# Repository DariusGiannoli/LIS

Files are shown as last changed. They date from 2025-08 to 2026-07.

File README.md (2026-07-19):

# LIS Haptic System

Firmware and Python APIs for controlling a 32-actuator haptic system over USB
serial or Bluetooth Low Energy (BLE).

The final implementation uses a three-byte command protocol, 32 intensity
levels, eight frequency levels, and sine or square waveforms.

## Architecture

```text
PC application
    |
    | USB serial or BLE
    v
ESP32-S3 controller
    |
    | 4 UART subchains, 8 actuators per subchain
    v
PIC16F18313 vibration units
```

## Repository structure

- `firmware/pic/` — PIC16F18313 actuator firmware and NeoPixel driver.
- `firmware/serial/` — ESP32-S3 USB serial controller.
- `firmware/ble/` — ESP32-S3 BLE controller.
- `python/` — Serial and BLE Python APIs.
- `3D/` — Final left and right enclosure models.
- `docs/` — Protocol and waveform documentation.

## Capabilities

- 32 individually addressable actuators (`0` to `31`).
- 32 intensity levels (`0` to `31`, encoded on five bits).
- Eight frequency levels (`0` to `7`, encoded on three bits).
- Sine and square waveforms.
- Individual and batched start/stop commands.
- USB serial and BLE transports.

## Requirements

### Python

- Python 3.9 or newer.
- `pyserial` for USB serial control.
- `bleak` for BLE control.

```bash
python3 -m venv .venv
source .venv/bin/activate
pip install -r requirements.txt
```

### ESP32-S3

- Arduino IDE or Arduino CLI with the ESP32 board package.
- Adafruit NeoPixel library.
- EspSoftwareSerial library.

### PIC16F18313

- MPLAB X IDE.
- MPLAB XC8 compiler.

Create an XC8 project containing all files from `firmware/pic/`, then flash the
same firmware to each vibration unit.

## Flashing the controller

Choose one ESP32-S3 controller firmware:

- USB serial: `firmware/serial/controller.ino`
- Bluetooth LE: `firmware/ble/controller.ino`

Both controllers translate the same PC-side three-byte frames into commands for
the four PIC UART subchains.

## Serial example

```python
from python.serial_api import SERIAL_API

api = SERIAL_API()
devices = api.get_serial_devices()

if not devices:
    raise RuntimeError("No serial controller found")

api.connect_serial_device(devices[0])

# Start actuator 0: sine wave, intensity 16/31, frequency index 3.
api.send_command(addr=0, duty=16, freq=3, start_or_stop=1, wave=1)

# Stop actuator 0.
api.send_command(addr=0, duty=0, freq=3, start_or_stop=0, wave=1)

api.disconnect_serial_device()
```

## BLE example

Flash `firmware/ble/controller.ino`. The controller advertises as
`VibraForge-BLE`.

```python
from python.ble_api import BLE_API

api = BLE_API()

if not api.connect_ble_device():
    raise RuntimeError("VibraForge-BLE not found")

api.send_command(addr=0, duty=16, freq=3, start_or_stop=1, wave=1)
api.send_command(addr=0, duty=0, freq=3, start_or_stop=0, wave=1)
api.disconnect_ble_device()
```

## Protocol

Commands sent from the PC contain three bytes:

| Byte | Content |
| --- | --- |
| 1 | Waveform, UART group, and start/stop mode |
| 2 | Actuator address inside the group |
| 3 | Five-bit intensity and three-bit frequency |

See [docs/protocol.md](docs/protocol.md) for the complete bit layout and
frequency table. See [docs/waveforms.md](docs/waveforms.md) for the sine and
square control strategies.

## Safety

- Always send a STOP command after a test.
- Avoid leaving actuators at high intensity for extended periods.
- Verify the motor supply and UART wiring before flashing or testing.
- Start new hardware tests at a low intensity.

## Legacy code

Previous experiments, ESP-NOW prototypes, and development versions are
preserved on the `legacy` branch and in the Git history. `main` contains only
the consolidated pre-hackathon implementation.

## Contact

Darius Giannoli — darius.giannoli(at)epfl.ch

### Acknowledgments

Grateful for Dr. Yang Chen's supervision and for Gabriel Taieb for his contributions to this work

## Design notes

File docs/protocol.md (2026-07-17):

# Three-byte command protocol

The Python APIs send one three-byte frame for each actuator command. Both the
USB serial and BLE controllers accept the same format.

## PC to ESP32-S3

### Byte 1 — waveform, group, and mode

```text
bit:   7   6   5   4   3   2   1   0
       W   0  G3  G2  G1  G0  M1  M0
```

- `W`: waveform (`0` = square, `1` = sine).
- `G`: UART subchain (`0` to `3`).
- `M`: mode (`00` = stop, `01` = start, `10` = soft stop).

### Byte 2 — local actuator address

```text
bit:   7   6   5   4   3   2   1   0
       0   0  A5  A4  A3  A2  A1  A0
```

The current hardware uses local addresses `0` to `7`. A global actuator address
is converted with:

```text
group = address // 8
local address = address % 8
```

### Byte 3 — intensity and frequency

```text
bit:   7   6   5   4   3   2   1   0
      D4  D3  D2  D1  D0  F2  F1  F0
```

- `D`: intensity (`0` to `31`).
- `F`: frequency index (`0` to `7`).

## ESP32-S3 to PIC16F18313

A STOP command is forwarded as one address byte:

```text
[local_address << 1 | 0]
```

A START command is forwarded as three bytes:

```text
[local_address << 1 | 1]
[1 | intensity on five bits]
[1 | waveform | frequency on three bits]
```

## Frequency indices

| Index | Approximate frequency |
| ---: | ---: |
| 0 | 123 Hz |
| 1 | 145 Hz |
| 2 | 170 Hz |
| 3 | 200 Hz |
| 4 | 235 Hz |
| 5 | 275 Hz |
| 6 | 322 Hz |
| 7 | 384 Hz |

The PIC firmware applies separate calibrated intensity lookup tables for sine
and square output.

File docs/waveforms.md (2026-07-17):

# Sine and square waveform control

The PIC16F18313 firmware supports two vibration modes. Both accept an intensity
value from `0` to `31`, but they apply it differently.

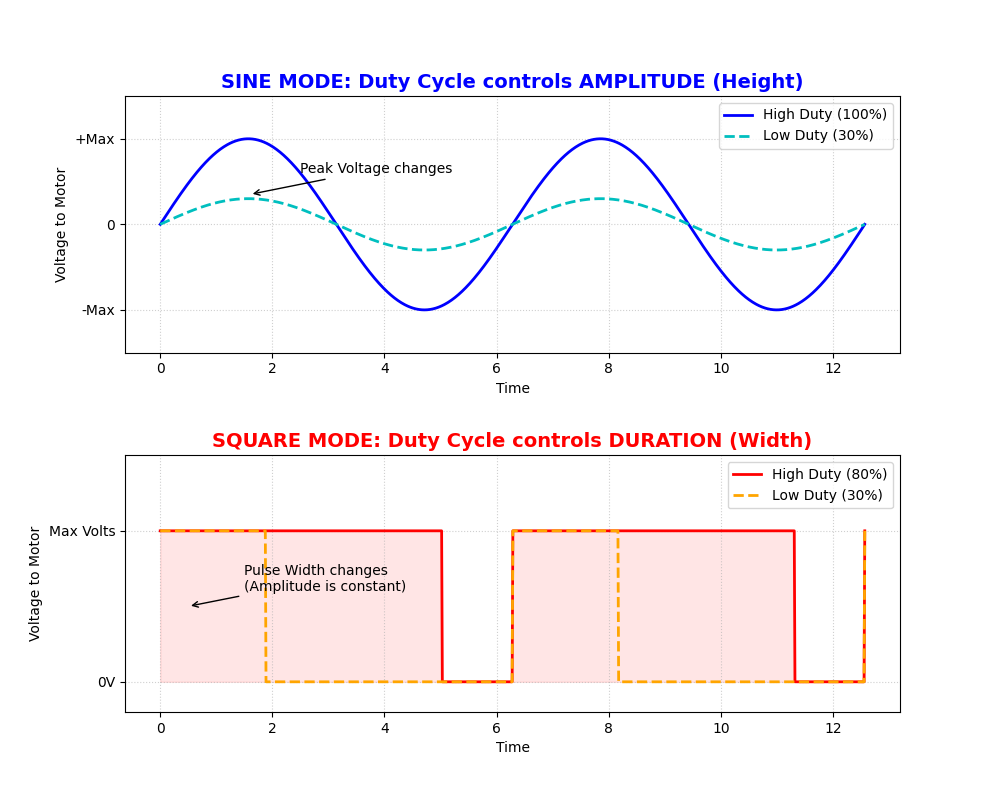
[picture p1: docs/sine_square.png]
Sine and square intensity comparison


## Square mode

Square mode controls the on-time of a full-power alternating signal. Increasing
the requested intensity widens each active portion of the waveform.

- Control domain: pulse width.
- Output: full voltage or off.
- Character: sharp and energetic.
- Typical use: impacts, alerts, and strong feedback.

The firmware uses a calibrated 32-entry lookup table so the perceived increase
is gradual at low levels and reaches full power at level `31`.

## Sine mode

Sine mode synthesizes a 64-sample waveform using a lookup table and sinusoidal
PWM. The requested intensity scales the peak amplitude.

- Control domain: amplitude.
- Output: PWM-reconstructed sine waveform.
- Character: smooth and precise.
- Typical use: textures and subtle feedback.

The H-bridge polarity changes at each zero crossing, while a high-frequency PWM
signal controls the magnitude of each sample.

## Summary

| Feature | Square | Sine |
| --- | --- | --- |
| Controlled quantity | Pulse width | Peak amplitude |
| Instantaneous output | Full power or off | Progressive PWM level |
| Perceived character | Sharp | Smooth |
| Intensity range | `0–31` | `0–31` |

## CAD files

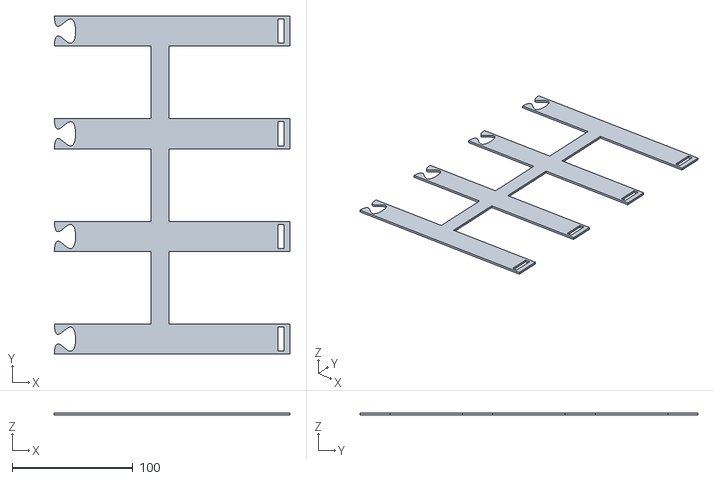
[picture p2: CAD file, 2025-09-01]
3D/Right.stl
195.0 x 279.8 x 2.00

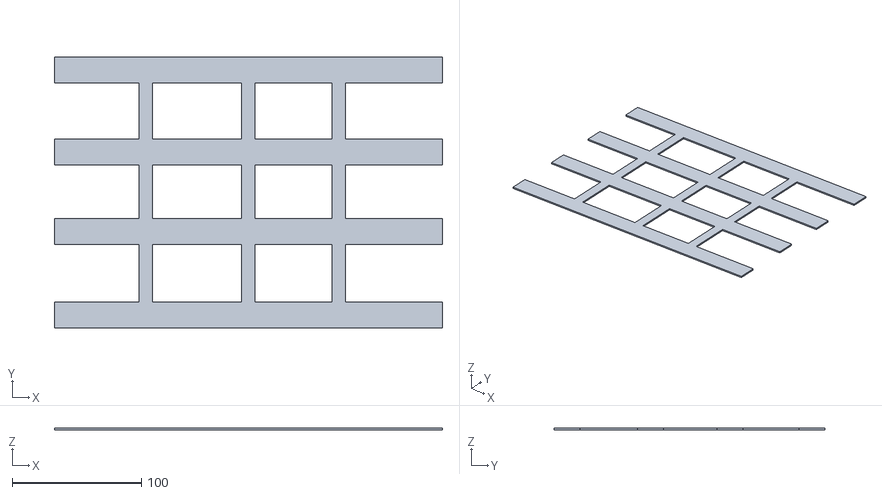
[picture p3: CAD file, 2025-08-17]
Experiment/3d/ddddd.stl
300.0 x 209.6 x 1.50

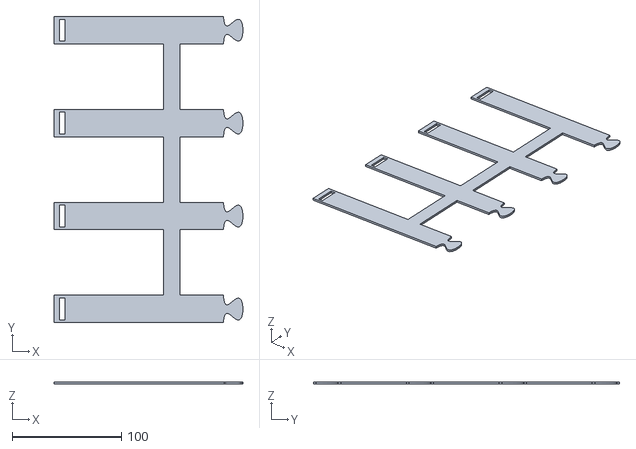
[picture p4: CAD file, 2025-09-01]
3D/Left.stl
172.7 x 279.8 x 2.00

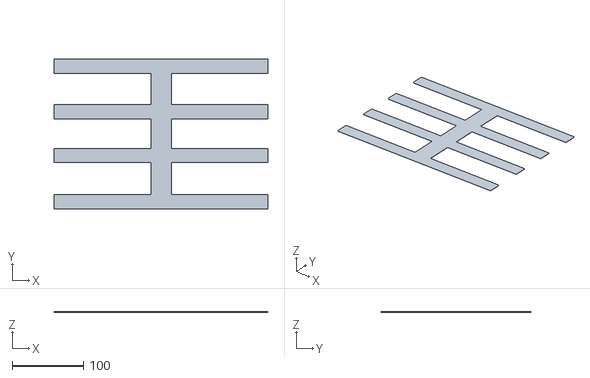
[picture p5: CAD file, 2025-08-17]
Experiment/3d/dv2.stl
300.0 x 209.6 x 1.50

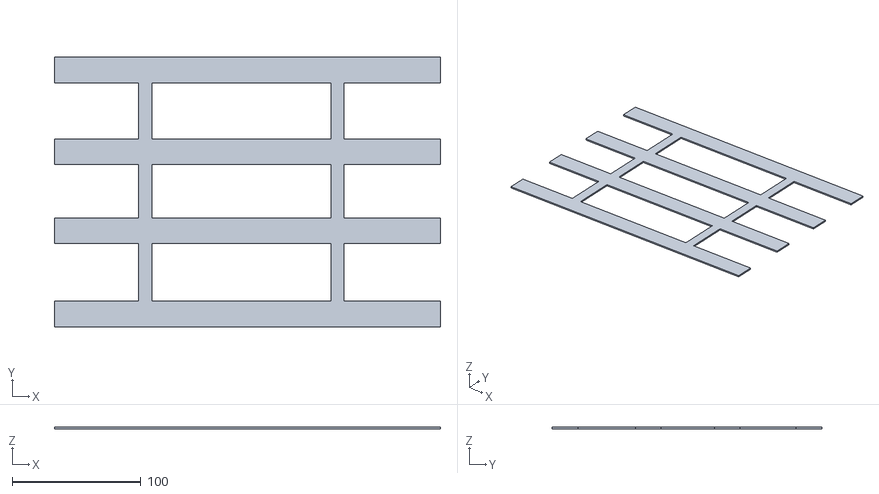
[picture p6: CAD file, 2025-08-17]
Experiment/3d/dv3.stl
300.0 x 209.6 x 1.50

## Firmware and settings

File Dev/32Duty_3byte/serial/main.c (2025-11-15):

/*  Vibration_Unit.c — PIC16F18313 @ 32 MHz (XC8 v3.10, -O0)
 *  Proto: Addr (MSB=0) → Data1 duty5 (MSB=1) → Data2 (MSB=1) = [1 0 0 W F2 F1 F0]
 *  wave=1 : TRUE-SINE (Timer1 + LUT 64 signée, PWM ~40kHz fixe via Timer2, routage PPS RA0/RA1)
 *  wave=0 : SQUARE (CWG + fenêtrage 0..199, inversion polarité à mi-cycle, traitement en main loop)
 */

#include <xc.h>
#include <stdint.h>
#include "neopixel_control.h"   // définit _XTAL_FREQ=32000000, SPI_Init(), sendColor_SPI()

// ==================== Config Bits ====================
#pragma config FEXTOSC=OFF, RSTOSC=HFINT32, CLKOUTEN=OFF, CSWEN=OFF, FCMEN=OFF
#pragma config MCLRE=ON, PWRTE=OFF, WDTE=OFF, LPBOREN=OFF, BOREN=OFF, BORV=LOW, PPS1WAY=OFF, STVREN=ON, DEBUG=OFF
#pragma config WRT=OFF, LVP=OFF, CP=OFF, CPD=OFF

// ==================== Etat / Protocole ====================
static volatile uint8_t buffer = 0;
static volatile uint8_t state  = 0;     // 0:addr, 1:duty, 2:wave+freq
static volatile uint8_t wave_mode  = 1; // 1=sine, 0=square
static volatile uint8_t duty5_raw  = 0; // 0..31
static volatile uint8_t duty_pct   = 0; // 0..99 (approx (duty5_raw / 32) * 100)
static volatile uint8_t freq_index = 3; // 0..7
static volatile uint8_t uart_led_flag = 0;

// ==================== LED ====================
static uint8_t color_index = 0;
static uint8_t color[3]    = {0,0,0};
static const uint8_t KEY16[16][3] = {
  {  0,  0,  0},  {  0, 32, 32},  {  0, 64, 64},  {  0,128,128},
  {  0,255,255},  {  0,255,128},  {  0,255,  0},  {128,255,  0},
  {255,255,  0},  {255,128,  0},  {255,  0,  0},  {255,  0,128},
  {255,  0,255},  {128,  0,255},  { 64,  0,255},  {255,255,255}
};
static inline void getColor32(uint8_t idx32, uint8_t out[3]){
    if(idx32 > 31) idx32 = 31;
    uint8_t seg = idx32 >> 1, odd = idx32 & 1;
    if(!odd || seg >= 15){
        out[0]=KEY16[seg][0]; out[1]=KEY16[seg][1]; out[2]=KEY16[seg][2];
    }else{
        out[0]=(uint8_t)((KEY16[seg][0]+KEY16[seg+1][0])>>1);
        out[1]=(uint8_t)((KEY16[seg][1]+KEY16[seg+1][1])>>1);
        out[2]=(uint8_t)((KEY16[seg][2]+KEY16[seg+1][2])>>1);
    }
}

// ==================== PWM (Timer2 / CCP1) ====================
// On utilise FMT=1 (right-aligned) en positionnant CCP1CON à 0b10011111.
// Duty 10 bits: CCPR1H = duty[9:2], CCPR1L<7:6> = duty[1:0].
static inline void set_pwm10(uint16_t dc10){
    // pas de DC1B*, pas de FMT bitfield → écriture directe
    CCPR1H = (uint8_t)(dc10 >> 2);
    CCPR1L = (uint8_t)((dc10 & 0x3u) << 6);
}

// ==================== TRUE-SINE (Timer1 + LUT signée 64) ====================
#define SINE_LEN 64u
#define CCP1_PPS_CODE 0x0C   // code PPS pour assigner CCP1 sur RA0/RA1
#define MIN_DRIVE_TKS 2u

static const int8_t SINE64_8[SINE_LEN] = {
     0,  12,  25,  37,  49,  60,  71,  81,
    90,  99, 106, 113, 118, 122, 125, 127,
   127, 127, 125, 122, 118, 113, 106,  99,
    90,  81,  71,  60,  49,  37,  25,  12,
     0, -12, -25, -37, -49, -60, -71, -81,
   -90, -99,-106,-113,-118,-122,-125,-127,
  -127,-127,-125,-122,-118,-113,-106, -99,
   -90, -81, -71, -60, -49, -37, -25, -12
};

// Fondamentales (Hz) et reloads Timer1 (tick = 1 µs, 64 échan.)
static const uint16_t FREQ_HZ[8]   = {123,145,170,200,235,275,322,384};
static const uint16_t T1_RELOAD[8] = {
    (uint16_t)(65536u - 127u),
    (uint16_t)(65536u - 108u),
    (uint16_t)(65536u -  92u),
    (uint16_t)(65536u -  78u),
    (uint16_t)(65536u -  66u),
    (uint16_t)(65536u -  57u),
    (uint16_t)(65536u -  49u),
    (uint16_t)(65536u -  41u)
};

static volatile uint8_t  phase_idx = 0;
static volatile int8_t   last_sign = 0;
static volatile uint16_t t1_reload = 0;
static volatile uint16_t scale     = 0;  // 0..top

// détacher CCP1 des pins & mettre RA0/RA1 à 0
static inline void coast_both(void){
    RA1PPS = 0; LATAbits.LATA1 = 0;
    RA0PPS = 0; LATAbits.LATA0 = 0;
}

// route demi-cycle: + → RA1=1 et PWM sur RA0 ; − → RA0=1 et PWM sur RA1
static inline void route_halfcycle(int8_t sign){
    if (sign > 0){
        RA0PPS = CCP1_PPS_CODE;  // PWM sur RA0
        RA1PPS = 0;
        LATAbits.LATA1 = 1; LATAbits.LATA0 = 0;
    } else {
        RA1PPS = CCP1_PPS_CODE;  // PWM sur RA1
        RA0PPS = 0;
        LATAbits.LATA0 = 1; LATAbits.LATA1 = 0;
    }
}

static inline void t1_apply_reload(uint8_t fidx){
    t1_reload = T1_RELOAD[fidx & 0x7u];
    T1CONbits.TMR1ON = 0;
    TMR1H = (uint8_t)(t1_reload >> 8);
    TMR1L = (uint8_t)(t1_reload & 0xFF);
    PIR1bits.TMR1IF = 0;
    T1CONbits.TMR1ON = 1;
}

// fixe l’amplitude 0..99 % → échelle 10 bits (top = 4*(PR2+1)-1)
static inline void lra_set_amp(uint8_t pct){
    if (pct > 100) pct = 100;
    uint16_t top = (uint16_t)(4u * ((uint16_t)PR2 + 1u) - 1u); // PR2=199 → top=799
    scale = (uint16_t)(((uint32_t)top * (uint32_t)pct + 50u) / 100u);
    if (!scale){ coast_both(); set_pwm10(0); }
}

// ==================== SQUARE (CWG + fenêtrage) ====================
static const uint8_t PR_val[8] = {85,72,60,52,44,37,32,27};
static volatile uint8_t index200 = 0;
static volatile uint8_t cwg_flag  = 0;
static volatile uint8_t duty_flag = 0;
static volatile uint8_t square_tick = 0;   // flag main-loop

static void square_processing(void){
    uint8_t on = (index200 < duty_pct) ||
                 (index200 >= 100 && index200 < (uint8_t)(100 + duty_pct));

    if (on){
        uint8_t half = (index200 >= 100);
        if (cwg_flag == 0 || (last_sign != (half ? -1 : +1))){
            CWG1CON0bits.EN = 0;
            if (!half){ CWG1CON1bits.POLA = 0; CWG1CON1bits.POLB = 0; last_sign = +1; }
            else       { CWG1CON1bits.POLA = 1; CWG1CON1bits.POLB = 1; last_sign = -1; }
            CWG1CON0bits.EN = 1;
            cwg_flag = 1;
        }
        if (duty_flag == 0){
            uint16_t top = (uint16_t)(4u * ((uint16_t)PR2 + 1u) - 1u);
            set_pwm10(top);
            duty_flag = 1;
        }
    }else{
        if (cwg_flag == 1){
            CWG1CON0bits.EN = 0;
            CWG1CON1bits.POLA = 0;
            CWG1CON1bits.POLB = 1; // sorties identiques → annule la diff
            CWG1CON0bits.EN = 1;
            cwg_flag = 0;
        }
        if (duty_flag == 1){
            set_pwm10(0);
            duty_flag = 0;
        }
    }
}

// ==================== UART ====================
static inline uint8_t make_addr_byte(uint8_t start, uint8_t addr6){
    return (uint8_t)((addr6 & 0x3Fu) << 1) | (start & 1u);
}
static inline void UART_Write(uint8_t d){ while(!TRMT){} TX1REG = d; }

static void UART_processing(void){
    if ((buffer >> 7) == 0){
        // ADDR
        uint8_t addr  = (buffer >> 1) & 0x3F;
        uint8_t start = (buffer & 1u);
        if (addr != 0){
            --addr; UART_Write(make_addr_byte(start, addr));
            state = 0; return;
        }else{
            if (!start){
                // STOP
                // SINE off
                T1CONbits.TMR1ON = 0; PIE1bits.TMR1IE = 0;
                coast_both(); set_pwm10(0);
                // SQUARE off
                T2CONbits.TMR2ON = 0; TMR2IE = 0;
                // CWG prêt pour square
                RA1PPS = 0b01000; RA0PPS = 0b01001; CWG1CON0bits.EN = 1;
                duty_pct = 0; cwg_flag = 0; duty_flag = 0; square_tick = 0;
                state = 0;
            }else{
                state = 1; // attendre duty
            }
            return;
        }
    }else{
        // DATA (MSB=1)
        if (state == 0){
            UART_Write(buffer); return;
        }else if (state == 1){
            duty5_raw = (uint8_t)(buffer & 0x1Fu); // 0..31
            state = 2; return;
        }else{
            uint8_t d2 = buffer & 0x7Fu;
            wave_mode  = (d2 >> 3) & 0x01u;
            freq_index = d2 & 0x07u;

            // ----- NEW: duty_pct from formula (no LUT) -----
            // duty_pct ≈ (duty5_raw / 32) * 100, integer arithmetic
            duty_pct = (uint8_t)(((uint16_t)duty5_raw * 100u) / 32u);

            uart_led_flag = 1;

            if (wave_mode){
                // ===== TRUE-SINE =====
                // Timer2 PWM fixe ~40 kHz (PR2=199, prescaler 1:1)
                T2CONbits.TMR2ON = 0;
                T2CONbits.T2CKPS = 0b00; // 1:1
                PR2 = 199; set_pwm10(0);
                TMR2 = 0; TMR2IF = 0; T2CONbits.TMR2ON = 1;

                // CCP1 PWM mode & format right-aligned (FMT=1 via valeur binaire)
                CCP1CON = 0b10011111; // P1M=00, FMT=1, CCP1M=1111 (PWM)

                // CWG OFF, pilotage direct PPS
                CWG1CON0bits.EN = 0;
                coast_both();

                // Timer1 1 µs tick, reload table
                T1CON = 0;
                T1CONbits.T1CKPS = 0b11; // 1:8 → 1 µs
                PIR1bits.TMR1IF = 0; PIE1bits.TMR1IE = 1;
                phase_idx = 0; last_sign = 0;
                lra_set_amp(duty_pct);
                t1_apply_reload(freq_index);
            }else{
                // ===== SQUARE =====
                // SINE OFF
                T1CONbits.TMR1ON = 0; PIE1bits.TMR1IE = 0;
                coast_both();   // libère RA0/RA1

                // CCP1 PWM mode & format right-aligned
                CCP1CON = 0b10011111;

                // CWG ON sur RA1/RA0 (entrées A/B)
                RA1PPS = 0b01000; RA0PPS = 0b01001; CWG1CON0bits.EN = 1;

                // Timer2 pour square : 1:4 + PR2 table
                T2CONbits.TMR2ON = 0;
                T2CONbits.T2CKPS = 0b01; // 1:4
                PR2 = PR_val[freq_index];
                TMR2 = 0; TMR2IF = 0; T2CONbits.TMR2ON = 1; TMR2IE = 1;

                index200 = 0; cwg_flag = 0; duty_flag = 0; square_tick = 0; last_sign = 0;
            }
            state = 0; return;
        }
    }
}

// ==================== Init ====================
static void usart_init(void){
    TRISA5 = 1; TRISA2 = 1; ANSELA = 0;
    RXPPS  = 0b00101;      // RA5 -> RX
    RA2PPS = 0b10100;      // TX  -> RA2
    RC1STA   = 0b10010000; // SPEN=1, CREN=1
    TX1STA   = 0b00100100; // BRGH=1, TXEN=1
    BAUD1CON = 0b00001000; // BRG16=1
    SP1BRGH  = 0; SP1BRGL = 68; // 115200 @32MHz
    RCIF=0; RCIE=1;
    __delay_us(100);
}

static void pwm_cwg_init(void){
    ANSELA = 0;
    TRISAbits.TRISA0 = 0;
    TRISAbits.TRISA1 = 0;

    // CCP1 PWM, format right-aligned (FMT=1 via valeur binaire)
    CCP1CON = 0b10011111;  // FMT=1, PWM
    set_pwm10(0);

    // Timer2 par défaut → PWM ~40 kHz (utilisé en SINE)
    T2CON = 0;
    T2CONbits.T2CKPS = 0b00;  // 1:1
    PR2 = 199; TMR2 = 0; TMR2IF = 0; T2CONbits.TMR2ON = 1;

    // CWG pour SQUARE (source = CCP1)
    RA1PPS = 0b01000; RA0PPS = 0b01001; // CWG1A/CWG1B
    CWG1CLKCON = 1; CWG1DAT = 0b00000011; // source = CCP1
    CWG1CON1 = 0; CWG1AS0 = 0b01111000;
    CWG1DBR = 0; CWG1DBF = 0;
    CWG1CON0 = 0b01000100; CWG1CON0bits.EN = 1;

    // IT
    TMR2IF = 0; TMR2IE = 0;                     // activé en SQUARE
    PIR1bits.TMR1IF = 0; PIE1bits.TMR1IE = 0;   // activé en SINE

    PEIE = 1; GIE = 1;
    __delay_us(100);
}

// ==================== ISR ====================
void __interrupt() ISR(void){
    if (RCIF){
        if (RC1STAbits.OERR){ RC1STAbits.CREN=0; RC1STAbits.CREN=1; }
        if (RC1STAbits.FERR){ volatile uint8_t junk=RC1REG; (void)junk; RCIF=0; return; }
        RCIF=0; buffer=RC1REG; UART_processing();
    }
    else if (PIR1bits.TMR1IF){ // TRUE-SINE tick
        PIR1bits.TMR1IF = 0;
        if (!wave_mode) return;

        // reload
        TMR1H = (uint8_t)(t1_reload >> 8);
        TMR1L = (uint8_t)(t1_reload & 0xFF);

        // phase suivante
        uint8_t i = phase_idx + 1u; if (i >= SINE_LEN) i = 0; phase_idx = i;
        int8_t  s8 = SINE64_8[i];
        int8_t  sgn = (s8 > 0) ? +1 : ((s8 < 0) ? -1 : last_sign);

        if (!scale){
            coast_both(); set_pwm10(0); last_sign = sgn; return;
        }
        if (sgn != last_sign){
            coast_both(); route_halfcycle(sgn); last_sign = sgn;
        }

        // amplitude : |s| (0..127) * scale / 128
        uint16_t mag = (uint16_t)(s8 >= 0 ? s8 : -s8);
        uint32_t tmp = (uint32_t)scale * (uint32_t)mag;
        uint16_t duty_fwd = (uint16_t)((tmp + 64u) >> 7); // /128 arrondi

        // converti en duty effectif 10 bits (top = 4*(PR2+1)-1)
        uint16_t top = (uint16_t)(4u * ((uint16_t)PR2 + 1u) - 1u); // PR2=199 → 799
        if (duty_fwd >= top) duty_fwd = top;
        set_pwm10(top - duty_fwd); // selon pont, inverse si besoin
    }
    else if (TMR2IF){
        TMR2IF = 0;
        if (!wave_mode){
            index200++; if (index200 == 200) index200 = 0;
            square_tick = 1;
        }
    }
}

// ==================== Main ====================
int main(void){
    usart_init();
    pwm_cwg_init();
    SPI_Init();

    set_pwm10(0);

    for(;;){
        // LED hors ISR (timing WS2812)
        if (uart_led_flag){
            uart_led_flag = 0;
            if (color_index != duty5_raw){
                color_index = duty5_raw;
                getColor32(color_index, color);
                uint8_t gie = INTCONbits.GIE; INTCONbits.GIE = 0;
                sendColor_SPI(color[0], color[1], color[2]);
                INTCONbits.GIE = gie;
            }
        }
        // Square fenêtrage en main loop
        if (square_tick){
            square_processing();
            square_tick = 0;
        }
    }
    return 0;
}

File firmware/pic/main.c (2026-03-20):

/* Vibration_Unit_FINAL.c — PIC16F18313
 * VERSION OPTIMISEE TAILLE (LIGHT) AVEC LUTS CALIBREES
 * * SINE Curve:   Min 4%  -> Mid 42% -> Max 100% (Progressive douce)
 * SQUARE Curve: Min 6%  -> Mid 20% -> 75%@65 -> Max 100% (Douce puis Agressive)
 */

#include <xc.h>
#include <stdint.h>
#include "neopixel_control.h" 

// ==================== Config Bits ====================
#pragma config FEXTOSC=OFF, RSTOSC=HFINT32, CLKOUTEN=OFF, CSWEN=OFF, FCMEN=OFF
#pragma config MCLRE=OFF, PWRTE=ON, WDTE=OFF, LPBOREN=OFF, BOREN=OFF, BORV=LOW, PPS1WAY=OFF, STVREN=ON, DEBUG=OFF
#pragma config WRT=OFF, LVP=OFF, CP=OFF, CPD=OFF

// ==================== Globals ====================
static volatile uint8_t buffer = 0;
static volatile uint8_t state  = 0;     
static volatile uint8_t wave_mode  = 1; 
static volatile uint8_t duty5_raw  = 0; 
static volatile uint8_t duty_pct   = 0; 
static volatile uint8_t freq_index = 3; 
static volatile uint8_t uart_led_flag = 0;

// ==================== LUTS (CALIBRATION UTILISATEUR) ====================

// SINE: 4 -> 42 -> 100 (Gamma ~1.3)
const uint8_t LUT_SINE[32] = {
    0,   4,   5,   7,   9,  11,  13,  15,
   17,  20,  23,  26,  29,  32,  35,  39,
   42,  46,  50,  54,  58,  62,  66,  71,
   75,  80,  85,  90,  95,  97,  99, 100
};

// SQUARE: 6 -> 20 -> 65 -> 100 (Multi-pente)
// 0-16: Progression lente (6->20). 16-24: Montée rapide (20->65). 24-31: Fin (65->100)
const uint8_t LUT_SQUARE[32] = {
    0,   6,   7,   8,   9,  10,  11,  12,
   13,  14,  15,  16,  17,  18,  19,  19,
   20,  26,  32,  38,  44,  50,  56,  62,
   68,  73,  78,  83,  88,  92,  96, 100
};

// ==================== LED LUT (Compacte) ====================
static uint8_t color[3] = {0,0,0};
static const uint8_t KEY16[16][3] = {
  {0,0,0}, {0,32,32}, {0,64,64}, {0,128,128},
  {0,255,255}, {0,255,128}, {0,255,0}, {128,255,0},
  {255,255,0}, {255,128,0}, {255,0,0}, {255,0,128},
  {255,0,255}, {128,0,255}, {64,0,255}, {255,255,255}
};

static void update_led_color(uint8_t idx32){
    if(idx32 > 31) idx32 = 31;
    uint8_t seg = idx32 >> 1;
    color[0] = KEY16[seg][0];
    color[1] = KEY16[seg][1];
    color[2] = KEY16[seg][2];
}

// ==================== PWM & TOOLS ====================
static inline void set_pwm10_isr(uint16_t dc10){
    CCPR1H = (uint8_t)(dc10 >> 2);
    CCPR1L = (uint8_t)((dc10 & 0x3u) << 6);
}

#define COAST_MACRO() { RA1PPS=0; LATAbits.LATA1=0; RA0PPS=0; LATAbits.LATA0=0; }

// ==================== TABLES SINE ====================
#define SINE_LEN 64u
#define CCP1_PPS_CODE 0x0C
static const int8_t SINE64_8[SINE_LEN] = {
     0, 12, 25, 37, 49, 60, 71, 81, 90, 99,106,113,118,122,125,127,
   127,127,125,122,118,113,106, 99, 90, 81, 71, 60, 49, 37, 25, 12,
     0,-12,-25,-37,-49,-60,-71,-81,-90,-99,-106,-113,-118,-122,-125,-127,
  -127,-127,-125,-122,-118,-113,-106,-99,-90,-81,-71,-60,-49,-37,-25,-12
};

static const uint16_t T1_RELOAD[8] = {
    65409, 65428, 65444, 65458, 65470, 65479, 65487, 65495 
};

static volatile uint8_t  phase_idx = 0;
static volatile int8_t   last_sign = 0;
static volatile uint16_t t1_reload = 0;
static volatile uint16_t scale     = 0;

static inline void route_halfcycle(int8_t sign){
    if (sign > 0){
        RA0PPS = CCP1_PPS_CODE; RA1PPS = 0;
        LATAbits.LATA1 = 1; LATAbits.LATA0 = 0;
    } else {
        RA1PPS = CCP1_PPS_CODE; RA0PPS = 0;
        LATAbits.LATA0 = 1; LATAbits.LATA1 = 0;
    }
}

static void lra_set_amp(uint8_t pct){
    if (pct > 100) pct = 100;
    uint32_t top = 799; 
    scale = (uint16_t)((top * pct + 50) / 100); 
    if (!scale){ COAST_MACRO(); set_pwm10_isr(0); }
}

// ==================== SQUARE ====================
static const uint8_t PR_val[8] = {85,72,60,52,44,37,32,27};
static volatile uint8_t index200 = 0;
static volatile uint8_t cwg_flag  = 0;
static volatile uint8_t duty_flag = 0;
static volatile uint8_t square_tick = 0;

static void square_processing(void){
    uint8_t on = 0;
    if (index200 < duty_pct) on = 1;
    else if (index200 >= 100 && index200 < (100 + duty_pct)) on = 1;

    if (on){
        uint8_t half = (index200 >= 100);
        if (cwg_flag == 0 || (last_sign != (half ? -1 : +1))){
            CWG1CON0bits.EN = 0;
            if (!half){ CWG1CON1bits.POLA=0; CWG1CON1bits.POLB=0; last_sign=1; }
            else       { CWG1CON1bits.POLA=1; CWG1CON1bits.POLB=1; last_sign=-1; }
            CWG1CON0bits.EN = 1; cwg_flag = 1;
        }
        if (duty_flag == 0){
            set_pwm10_isr(799); // Top direct pour max power square
            duty_flag = 1;
        }
    }else{
        if (cwg_flag == 1){
            CWG1CON0bits.EN = 0; CWG1CON1bits.POLA=0; CWG1CON1bits.POLB=1;
            CWG1CON0bits.EN = 1; cwg_flag = 0;
        }
        if (duty_flag == 1){
            set_pwm10_isr(0); duty_flag = 0;
        }
    }
}

// ==================== UART ====================
static void UART_Write(uint8_t d){ while(!TRMT){} TX1REG = d; }
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

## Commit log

2025-07-24 new paper modifs (three actuators for phantom
2025-08-21 Location working
    [ddddd.stl, dv2.stl, dv3.stl]
2025-09-01 new 3d
    [ddddd.stl, dv2.stl, dv3.stl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]
2025-09-17 Bit fix problem resolved
    [serial_api.py]
2025-11-10 first optimized version but still have bugs in Unity
    [ble.ino]
2025-11-11 extended sinus sine and changed the 32 to 100 maping for softer curve and less noise
    [Centered_Sinus.c, optimized_sine.c]
2025-11-23 not overheating version of sine / square switch
    [main.c, main_linear.c, serial_api.py]
2025-11-25 arm mapping
2026-07-16 cleaned version V1
    [ddddd.stl, dv2.stl, dv3.stl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]
2026-07-16 Update README to reflect current project structure
    Removed outdated sections and added author name.
